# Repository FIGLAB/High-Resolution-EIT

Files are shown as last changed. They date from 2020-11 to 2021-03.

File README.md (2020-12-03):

# High-Resolution-EIT

The high resolution Electrical Impedance Tomograph (EIT) project is provided for academic and non-commercial research. This project is based on our publication at ACM UIST 2016: https://dl.acm.org/doi/abs/10.1145/2984511.2984574

## ACM Ref

Yang Zhang, Robert Xiao, and Chris Harrison. 2016. Advancing Hand Gesture Recognition with High Resolution Electrical Impedance Tomography. In Proceedings of the 29th Annual Symposium on User Interface Software and Technology (UIST '16). Association for Computing Machinery, New York, NY, USA, 843–850. DOI:https://doi.org/10.1145/2984511.2984574

## BibTex

```
@inproceedings{10.1145/2984511.2984574,
author = {Zhang, Yang and Xiao, Robert and Harrison, Chris},
title = {Advancing Hand Gesture Recognition with High Resolution Electrical Impedance Tomography},
year = {2016},
isbn = {9781450341899},
publisher = {Association for Computing Machinery},
address = {New York, NY, USA},
url = {https://doi.org/10.1145/2984511.2984574},
doi = {10.1145/2984511.2984574},
abstract = {Electrical Impedance Tomography (EIT) was recently employed in the HCI domain to detect hand gestures using an instrumented smartwatch. This prior work demonstrated great promise for non-invasive, high accuracy recognition of gestures for interactive control. We introduce a new system that offers improved sampling speed and resolution. In turn, this enables superior interior reconstruction and gesture recognition. More importantly, we use our new system as a vehicle for experimentation ' we compare two EIT sensing methods and three different electrode resolutions. Results from in-depth empirical evaluations and a user study shed light on the future feasibility of EIT for sensing human input.},
booktitle = {Proceedings of the 29th Annual Symposium on User Interface Software and Technology},
pages = {843–850},
numpages = {8},
keywords = {hand gestures, eit, electrical impedance tomography, biometrics, smartwatch, bio-impedance, input},
location = {Tokyo, Japan},
series = {UIST '16}
}
```

## Contact

For interests in commercialization, please reach out to CMU CTTEC for details at innovation@cmu.edu

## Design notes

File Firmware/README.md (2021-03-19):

# Firmware

IDE: Arduino with Teensyduino add-on 

Arduino: https://www.arduino.cc/en/software/
Teensyduino: https://www.pjrc.com/teensy/teensyduino.html

Firmware was tested with Arduino V1.6.5 and Teensyduino V1.40.

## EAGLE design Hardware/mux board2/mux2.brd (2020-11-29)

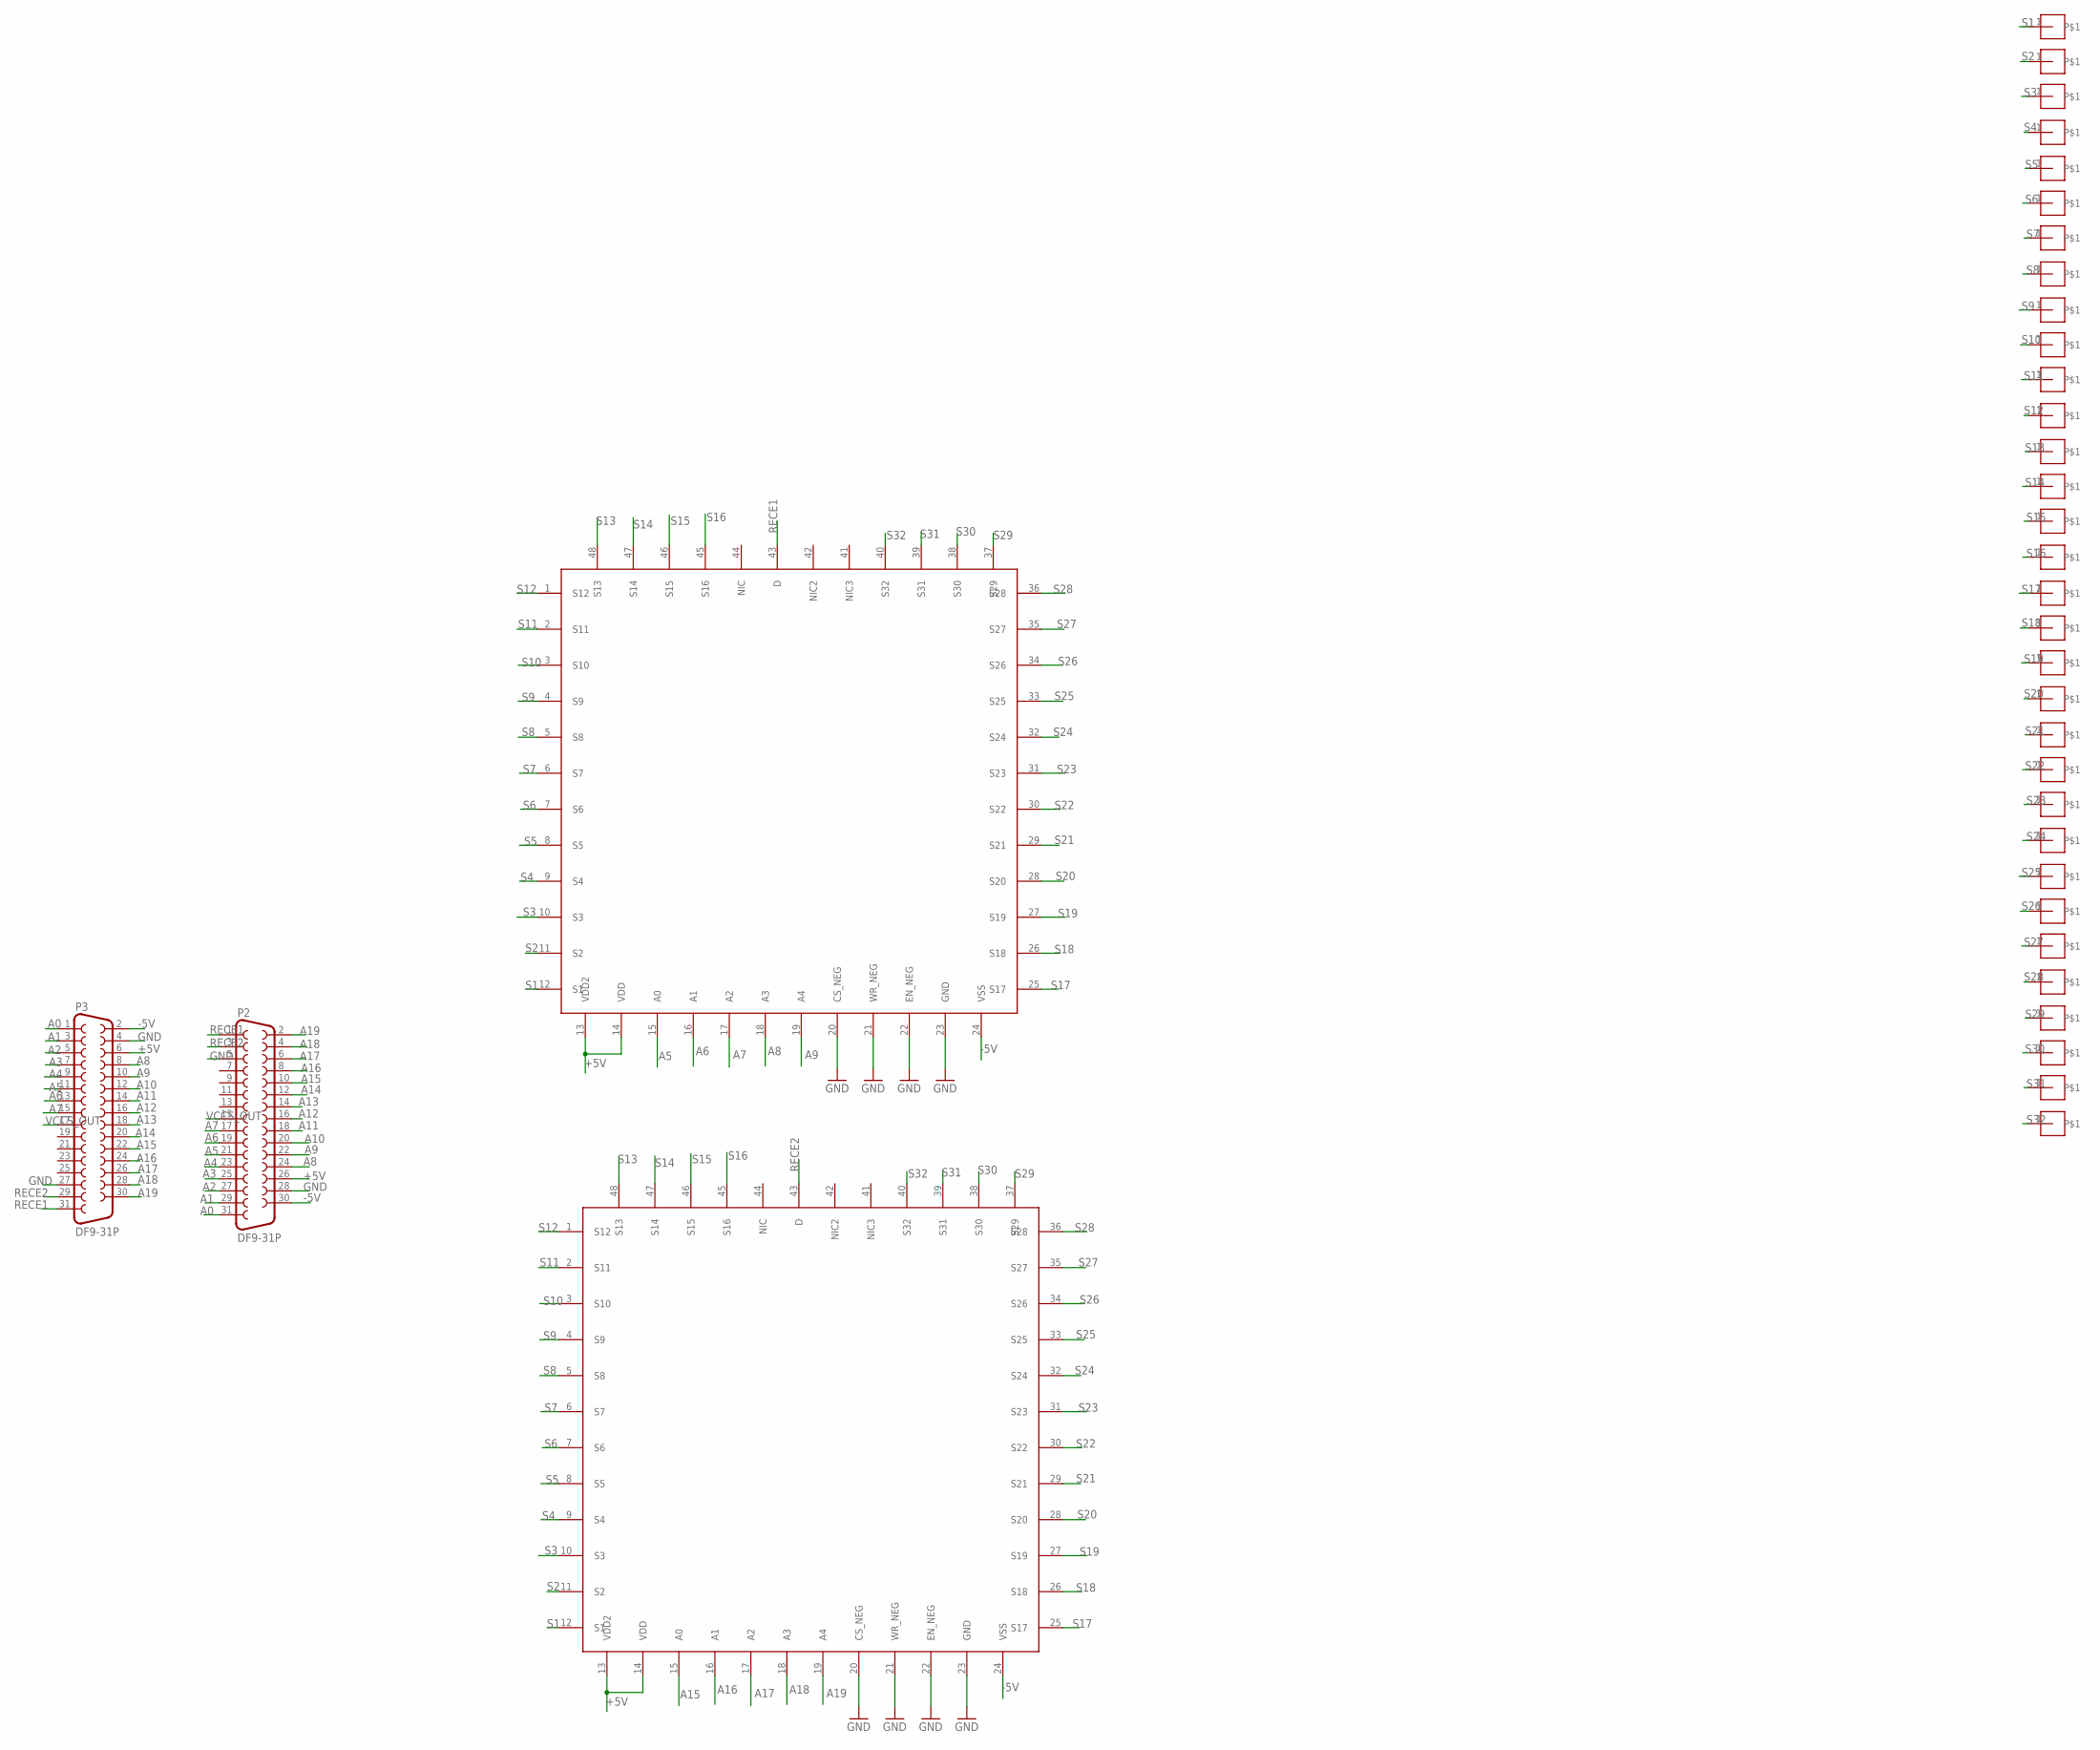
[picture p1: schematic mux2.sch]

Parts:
P2, P3: DF9-31P
U$25, U$26, U$27, U$28, U$29, U$30, U$31, U$32, U$33, U$34, U$35, U$36, U$37, U$38, U$39, U$40, U$41, U$42, U$43, U$44, U$45, U$46, U$47, U$48, U$49, U$50, U$51, U$52, U$53, U$54, U$55, U$56: M01
U$73, U$74: ADG732; TQFP48

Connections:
+5V: P2.26, P3.6, U$73.13 (VDD2), U$73.14 (VDD), U$74.13 (VDD2), U$74.14 (VDD)
-5V: P2.30, P3.2, U$73.24 (VSS), U$74.24 (VSS)
A0: P2.31, P3.1
A1: P2.29, P3.3
A2: P2.27, P3.5
A3: P2.25, P3.7
A4: P2.23, P3.9
A5: P2.21, P3.11, U$74.15 (A0)
A6: P2.19, P3.13, U$74.16 (A1)
A7: P2.17, P3.15, U$74.17 (A2)
A8: P2.24, P3.8, U$74.18 (A3)
A9: P2.22, P3.10, U$74.19 (A4)
A10: P2.20, P3.12
A11: P2.18, P3.14
A12: P2.16, P3.16
A13: P2.14, P3.18
A14: P2.12, P3.20
A15: P2.10, P3.22, U$73.15 (A0)
A16: P2.8, P3.24, U$73.16 (A1)
A17: P2.6, P3.26, U$73.17 (A2)
A18: P2.4, P3.28, U$73.18 (A3)
A19: P2.2, P3.30, U$73.19 (A4)
GND: P2.5, P2.28, P3.4, P3.27, U$73.20 (CS_NEG), U$73.21 (WR_NEG), U$73.22 (EN_NEG), U$73.23 (GND), U$74.20 (CS_NEG), U$74.21 (WR_NEG), U$74.22 (EN_NEG), U$74.23 (GND)
RECE1: P2.1, P3.31, U$74.43 (D)
RECE2: P2.3, P3.29, U$73.43 (D)
S1: U$25.1, U$73.12 (S1), U$74.12 (S1)
S2: U$26.1, U$73.11 (S2), U$74.11 (S2)
S3: U$27.1, U$73.10 (S3), U$74.10 (S3)
S4: U$28.1, U$73.9 (S4), U$74.9 (S4)
S5: U$29.1, U$73.8 (S5), U$74.8 (S5)
S6: U$30.1, U$73.7 (S6), U$74.7 (S6)
S7: U$31.1, U$73.6 (S7), U$74.6 (S7)
S8: U$32.1, U$73.5 (S8), U$74.5 (S8)
S9: U$33.1, U$73.4 (S9), U$74.4 (S9)
S10: U$34.1, U$73.3 (S10), U$74.3 (S10)
S11: U$35.1, U$73.2 (S11), U$74.2 (S11)
S12: U$36.1, U$73.1 (S12), U$74.1 (S12)
S13: U$37.1, U$73.48 (S13), U$74.48 (S13)
S14: U$38.1, U$73.47 (S14), U$74.47 (S14)
S15: U$39.1, U$73.46 (S15), U$74.46 (S15)
S16: U$40.1, U$73.45 (S16), U$74.45 (S16)
S17: U$41.1, U$73.25 (S17), U$74.25 (S17)
S18: U$42.1, U$73.26 (S18), U$74.26 (S18)
S19: U$43.1, U$73.27 (S19), U$74.27 (S19)
S20: U$44.1, U$73.28 (S20), U$74.28 (S20)
S21: U$45.1, U$73.29 (S21), U$74.29 (S21)
S22: U$46.1, U$73.30 (S22), U$74.30 (S22)
S23: U$47.1, U$73.31 (S23), U$74.31 (S23)
S24: U$48.1, U$73.32 (S24), U$74.32 (S24)
S25: U$49.1, U$73.33 (S25), U$74.33 (S25)
S26: U$50.1, U$73.34 (S26), U$74.34 (S26)
S27: U$51.1, U$73.35 (S27), U$74.35 (S27)
S28: U$52.1, U$73.36 (S28), U$74.36 (S28)
S29: U$53.1, U$73.37 (S29), U$74.37 (S29)
S30: U$54.1, U$73.38 (S30), U$74.38 (S30)
S31: U$55.1, U$73.39 (S31), U$74.39 (S31)
S32: U$56.1, U$73.40 (S32), U$74.40 (S32)
VCCS_OUT: P2.15, P3.17

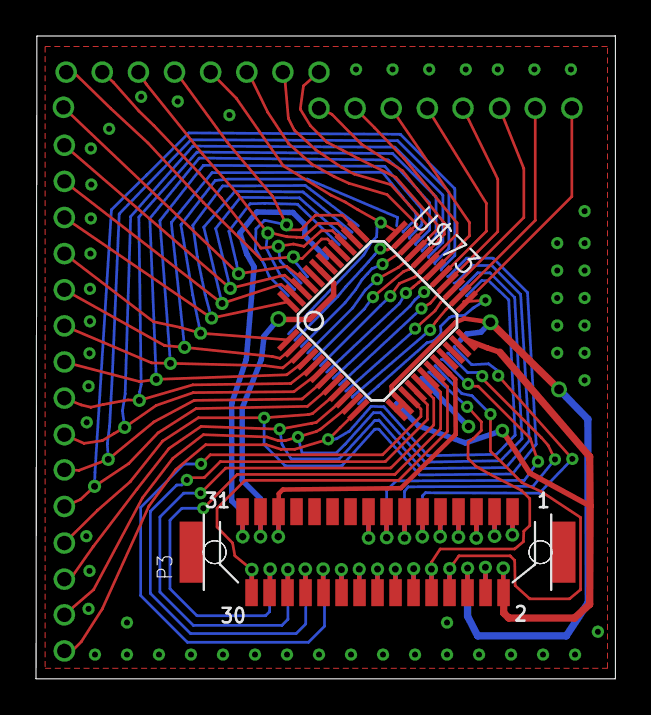
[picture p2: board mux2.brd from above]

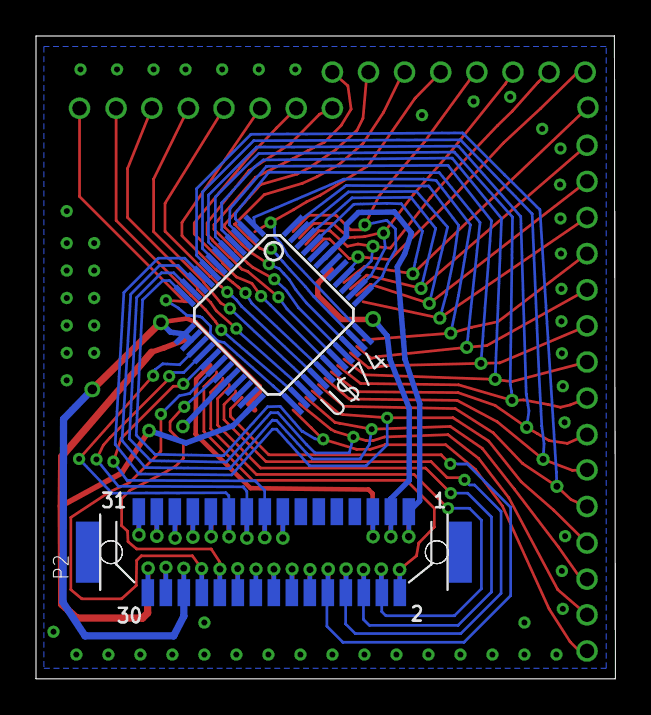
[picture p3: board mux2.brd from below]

Board: 2 copper layers, 32.2 x 35.7 mm, 36 parts (2 on the bottom side), 58 nets.

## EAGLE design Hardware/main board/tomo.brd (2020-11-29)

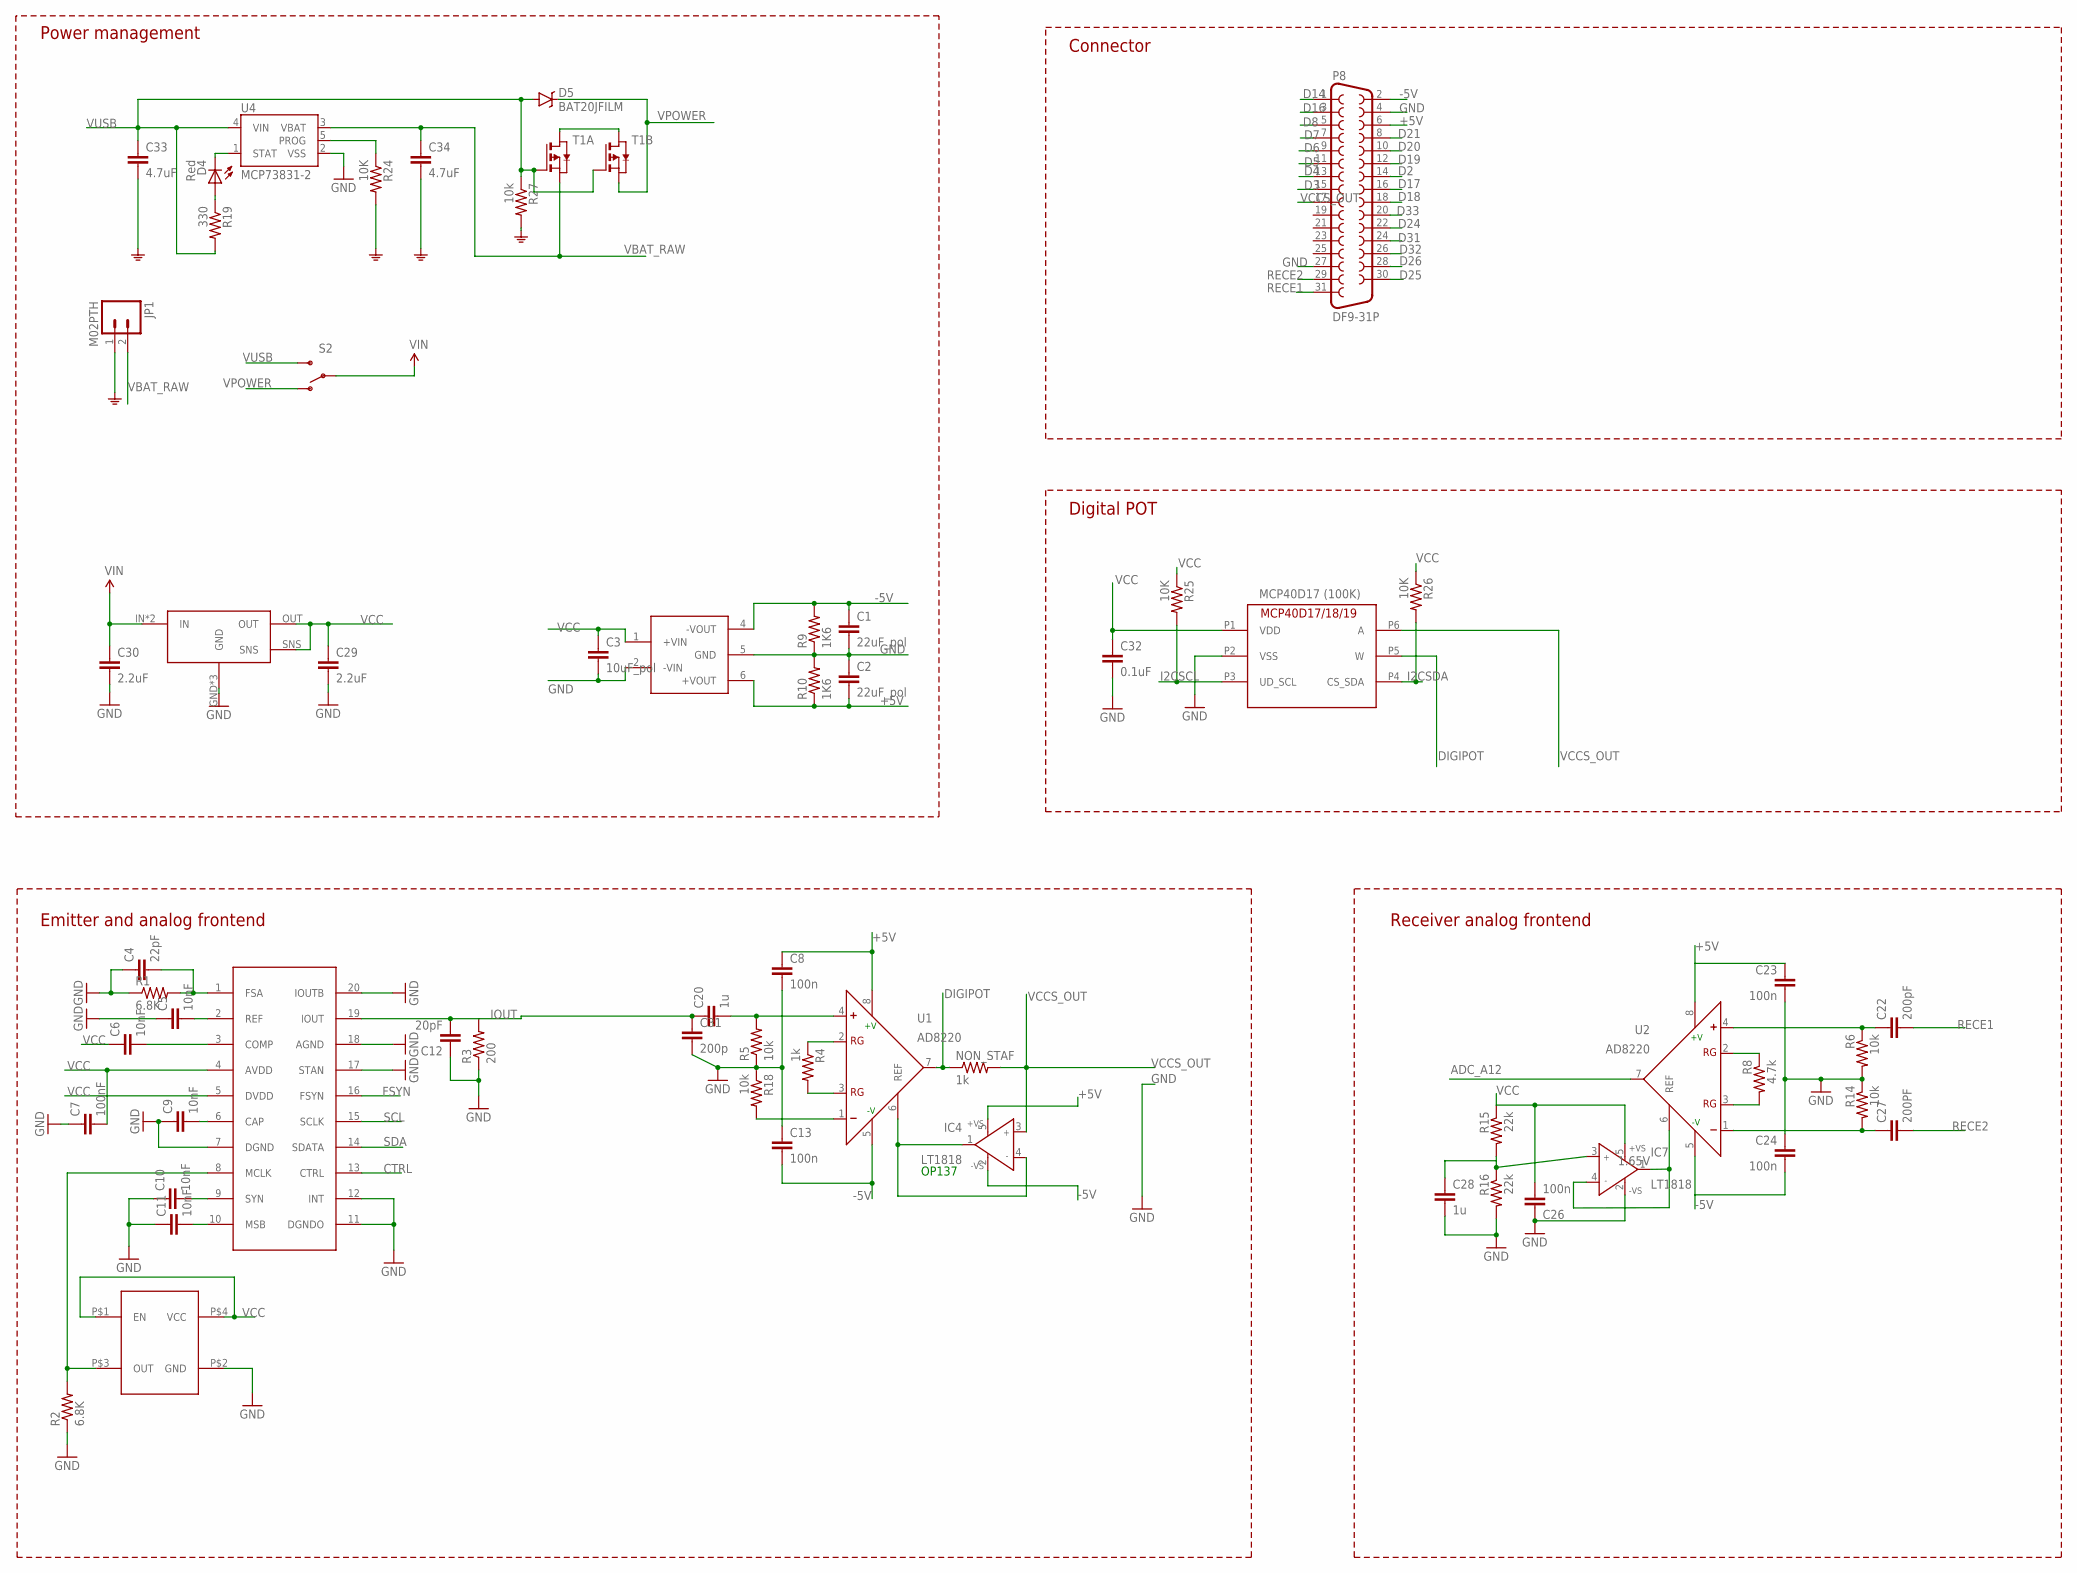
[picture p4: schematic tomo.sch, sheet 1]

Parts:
C1, C2: 22uF_pol; 0603-CAP
C3: 10uF_pol; 0603-CAP
C4: 22pF; 0603-CAP
C5, C6, C9, C10, C11: 10nF; 0603-CAP
C7: 100nF; 0603-CAP
C8, C13, C23, C24, C26: 100n; 0603-CAP
C12: 20pF; 0603-CAP
C20, C28: 1u; 0603-CAP
C22: 200pF; 0603-CAP
C27: 200PF; 0603-CAP
C29, C30: 2.2uF; 0402-CAP
C31: 200p; 0603-CAP
C32: 0.1uF; 0402-CAP
C33, C34: 4.7uF; 0402-CAP
D4: Red; LED-0603
D5: BAT20JFILM; SOD-323
IC4, IC7: LT1818; SOT23-5
JP1: M02PTH; 1X02
LP1: LP38691SD; WSON_6
NON_STAF: 1k; 0603-RES
P8: DF9-31P
R1, R2: 6.8K; 0603
R3: 200; 0603
R4: 1k; 0603-RES
R5, R18: 10k; 0603-RES
R6, R14: 10k; 0603
R8: 4.7k; 0603
R9, R10: 1K6; 0603-RES
R15, R16: 22k; 0603
R19: 330; 0402-RES
R24, R25, R26: 10K; 0402-RES
R27: 10k; 0402-RES
S2: SWITCH-SPDT-SMD-A; SWITCH-SPST-SMD-A
T1: BSS84DW; SOT363
U1, U2: AD8220; MSOP8
U4: MCP73831-2; SOT23-5
U$2: AD5930; TSSOP-20
U$3: OSC
U$4: DCDC_CONVERTOR
U$6: MCP40D17/18/19; SC70-6

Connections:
1.65V: IC7.1 (OUT), IC7.4 (IN-), U2.6 (REF)
+5V: C2.2, C8.1, C23.1, IC4.5 (+VS), P8.6, R10.1, U1.8 (+V), U2.8 (+V), U$4.6 (+VOUT)
-5V: C1.1, C13.2, C24.2, IC4.2 (-VS), P8.2, R9.2, U1.5 (-V), U2.5 (-V), U$4.4 (-VOUT)
ADC_A12: U2.7 (OUT); also elsewhere on the board
CTRL: U$2.13 (CTRL); also elsewhere on the board
D2: P8.14; also elsewhere on the board
D3: P8.15; also elsewhere on the board
D4: P8.13; also elsewhere on the board
D5: P8.11; also elsewhere on the board
D6: P8.9; also elsewhere on the board
D7: P8.7; also elsewhere on the board
D8: P8.5; also elsewhere on the board
D14: P8.1; also elsewhere on the board
D16: P8.3; also elsewhere on the board
D17: P8.16; also elsewhere on the board
D18: P8.18; also elsewhere on the board
D19: P8.12; also elsewhere on the board
D20: P8.10; also elsewhere on the board
D21: P8.8; also elsewhere on the board
D24: P8.22; also elsewhere on the board
D25: P8.30; also elsewhere on the board
D26: P8.28; also elsewhere on the board
D31: P8.24; also elsewhere on the board
D32: P8.26; also elsewhere on the board
D33: P8.20; also elsewhere on the board
DIGIPOT: NON_STAF.1, U1.7 (OUT), U$6.P5 (W)
FSYN: U$2.16 (FSYN); also elsewhere on the board
GND: C1.2, C2.1, C3.2, C4.1, C5.1, C7.1, C8.2, C9.1, C10.1, C11.1, C12.1, C13.1, C23.2, C24.1, C26.1, C28.2, C29.2, C30.2, C31.2, C32.2, C33.2, C34.2, IC7.2 (-VS), JP1.1, LP1.GND, LP1.N/C (GND), LP1.THERMAL (GND), P8.4, P8.27, R1.1, R2.1, R3.1, R5.1, R6.2, R9.1, R10.2, R14.1, R16.2, R18.1, R24.2, R27.2, U4.2 (VSS), U$2.7 (DGND), U$2.11 (DGNDO), U$2.12 (INT), U$2.17 (STAN), U$2.18 (AGND), U$2.20 (IOUTB), U$3.P$2 (GND), U$4.2 (-VIN), U$4.5 (GND), U$6.P2 (VSS); also elsewhere on the board
I2CSCL: R25.2, U$6.P3 (UD_SCL); also elsewhere on the board
I2CSDA: R26.2, U$6.P4 (CS_SDA); also elsewhere on the board
IOUT: C12.2, C20.1, C31.1, R3.2, U$2.19 (IOUT)
unnamed: C4.2, R1.2, U$2.1 (FSA)
unnamed: C6.2, U$2.3 (COMP)
unnamed: C5.2, U$2.2 (REF)
unnamed: C9.2, U$2.6 (CAP)
unnamed: R2.2, U$2.8 (MCLK), U$3.P$3 (OUT)
unnamed: C10.2, U$2.9 (SYN)
unnamed: C11.2, U$2.10 (MSB)
unnamed: R4.1, U1.2 (RG)
unnamed: C28.1, IC7.3 (IN+), R15.2, R16.1
unnamed: C20.2, R5.2, U1.4 (+)
unnamed: R4.2, U1.3 (RG)
unnamed: IC4.1 (OUT), IC4.4 (IN-), U1.6 (REF)
unnamed: R18.2, U1.1 (-)
unnamed: D4.A, R19.1
unnamed: T1.3 (D), T1.6 (D)
unnamed: C22.1, R6.1, U2.4 (+)
unnamed: C27.1, R14.2, U2.1 (-)
unnamed: R8.1, U2.2 (RG)
unnamed: R8.2, U2.3 (RG)
PROG: R24.1, U4.5 (PROG)
RECE1: C22.2, P8.31
RECE2: C27.2, P8.29
SCL: U$2.15 (SCLK); also elsewhere on the board
SDA: U$2.14 (SDATA); also elsewhere on the board
STAT: D4.C, U4.1 (STAT)
VBAT_RAW: C34.1, JP1.2, T1.4 (S), U4.3 (VBAT)
VCC: C3.1, C6.1, C7.2, C26.2, C29.1, C32.1, IC7.5 (+VS), LP1.OUT, LP1.SNS, R15.1, R25.1, R26.1, U$2.4 (AVDD), U$2.5 (DVDD), U$3.P$1 (EN), U$3.P$4 (VCC), U$4.1 (+VIN), U$6.P1 (VDD)
VCCS_OUT: IC4.3 (IN+), NON_STAF.2, P8.17, U$6.P6 (A)
VIN: C30.1, LP1.IN, LP1.IN2 (IN), S2.2; also elsewhere on the board
VPOWER: D5.C, S2.1 (O), T1.1 (S)
VUSB: C33.1, D5.A, R19.2, R27.1, S2.3 (S), T1.2 (G), T1.5 (G), U4.4 (VIN); also elsewhere on the board

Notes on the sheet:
OP137
MCP40D17 (100K)
Power management
Connector
Digital POT
Emitter and analog frontend
Receiver analog frontend

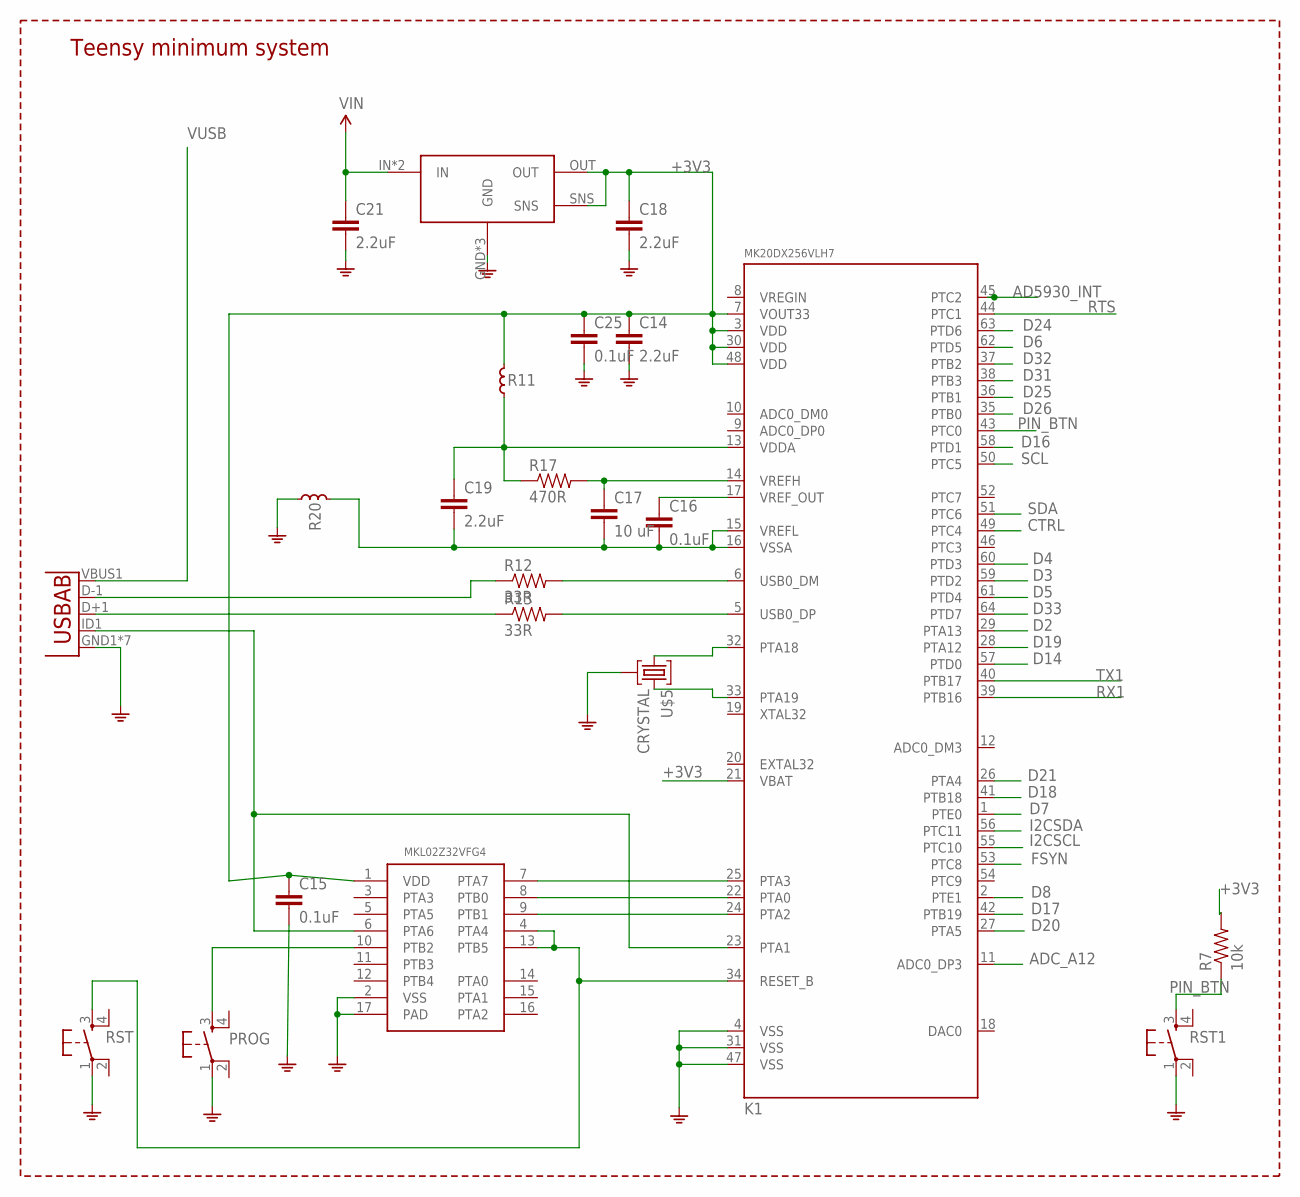
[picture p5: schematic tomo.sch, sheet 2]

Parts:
C14: 2.2uF; 0603-CAP
C15, C16, C25: 0.1uF; 0402-CAP
C17: 10 uF; 0402-CAP
C18, C19, C21: 2.2uF; 0402-CAP
K1: MK20DX256VLH7; LQFP64-05
LP38691: LP38691SD; WSON_6
PROG: KMR211GLFS; TACTILE_SWITCH_SMD
R7: 10k; 0402-RES
R11, R20: FERRITE; L0603
R12, R13: 33R; 0402-RES
R17: 470R; 0402-RES
RST, RST1: KMR211GLFS; TACTILE_SWITCH_SMD
U5: USB""; USB-MICRO-SMD
U$5: CRYSTAL
U$14: MKL02Z32VFG4_; QFN16_3X3

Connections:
+3V3: C14.1, C15.1, C18.1, C25.1, K1.3 (VDD), K1.7 (VOUT33), K1.21 (VBAT), K1.30 (VDD), K1.48 (VDD), LP38691.OUT, LP38691.SNS, R7.2, R11.2, U$14.1 (VDD); also elsewhere on the board
AD5930_INT: K1.45 (PTC2)
ADC_A12: K1.11 (ADC0_DP3); also elsewhere on the board
CTRL: K1.49 (PTC4); also elsewhere on the board
D2: K1.29 (PTA13); also elsewhere on the board
D3: K1.59 (PTD2); also elsewhere on the board
D4: K1.60 (PTD3); also elsewhere on the board
D5: K1.61 (PTD4); also elsewhere on the board
D6: K1.62 (PTD5); also elsewhere on the board
D7: K1.1 (PTE0); also elsewhere on the board
D8: K1.2 (PTE1); also elsewhere on the board
D14: K1.57 (PTD0); also elsewhere on the board
D16: K1.58 (PTD1); also elsewhere on the board
D17: K1.42 (PTB19); also elsewhere on the board
D18: K1.41 (PTB18); also elsewhere on the board
D19: K1.28 (PTA12); also elsewhere on the board
D20: K1.27 (PTA5); also elsewhere on the board
D21: K1.26 (PTA4); also elsewhere on the board
D24: K1.63 (PTD6); also elsewhere on the board
D25: K1.36 (PTB1); also elsewhere on the board
D26: K1.35 (PTB0); also elsewhere on the board
D31: K1.38 (PTB3); also elsewhere on the board
D32: K1.37 (PTB2); also elsewhere on the board
D33: K1.64 (PTD7); also elsewhere on the board
FSYN: K1.53 (PTC8); also elsewhere on the board
GND: C14.2, C15.2, C18.2, C21.2, C25.2, K1.4 (VSS), K1.31 (VSS), K1.47 (VSS), LP38691.GND, LP38691.N/C (GND), LP38691.THERMAL (GND), PROG.1, R20.1, RST.1, RST1.1, U5.GND1 (GND), U5.P$1 (GND), U5.P$2 (GND), U5.P$3 (GND), U5.P$4 (GND), U5.P$5 (GND), U5.P$6 (GND), U$5.GND1 (2), U$5.GND2 (2), U$14.2 (VSS), U$14.17 (PAD); also elsewhere on the board
I2CSCL: K1.55 (PTC10); also elsewhere on the board
I2CSDA: K1.56 (PTC11); also elsewhere on the board
unnamed: K1.24 (PTA2), U$14.9 (PTB1)
unnamed: K1.5 (USB0_DP), R13.2
unnamed: K1.6 (USB0_DM), R12.2
unnamed: R13.1, U5.D+1 (D+)
unnamed: C16.1, K1.17 (VREF_OUT)
unnamed: R12.1, U5.D-1 (D-)
unnamed: K1.23 (PTA1), U5.ID1 (USBID), U$14.6 (PTA6)
unnamed: K1.22 (PTA0), U$14.8 (PTB0)
unnamed: K1.32 (PTA18), U$5.SIG1 (1)
unnamed: K1.33 (PTA19), U$5.SIG2 (3)
unnamed: C17.1, K1.14 (VREFH), R17.2
unnamed: C16.2, C17.2, C19.2, K1.15 (VREFL), K1.16 (VSSA), R20.2
unnamed: C19.1, K1.13 (VDDA), R11.1, R17.1
unnamed: PROG.3, U$14.10 (PTB2)
unnamed: K1.25 (PTA3), U$14.7 (PTA7)
PIN_BTN: K1.43 (PTC0), R7.1, RST1.3
RST: K1.34 (RESET_B), RST.3, U$14.4 (PTA4), U$14.13 (PTB5)
RTS: K1.44 (PTC1); also elsewhere on the board
RX1: K1.39 (PTB16); also elsewhere on the board
SCL: K1.50 (PTC5); also elsewhere on the board
SDA: K1.51 (PTC6); also elsewhere on the board
TX1: K1.40 (PTB17); also elsewhere on the board
VIN: C21.1, LP38691.IN, LP38691.IN2 (IN); also elsewhere on the board
VUSB: U5.VBUS1 (VBUS); also elsewhere on the board

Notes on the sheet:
Teensy minimum system

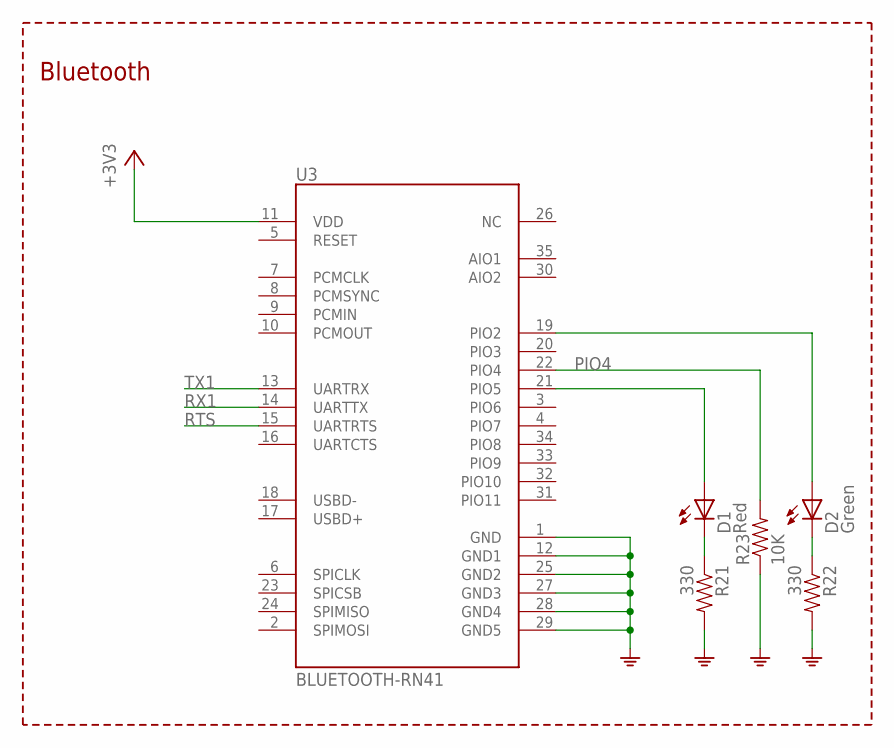
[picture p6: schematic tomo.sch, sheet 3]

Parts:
D1: Red; LED-0603
D2: Green; LED-0603
R21, R22: 330; 0402-RES
R23: 10K; 0402-RES
U3: BLUETOOTH-RN41; RN41

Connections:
+3V3: U3.11 (VDD); also elsewhere on the board
D1: D1.C, R21.1
D9: D2.C, R22.1
GND: R21.2, R22.2, R23.1, U3.1 (GND), U3.12 (GND1), U3.25 (GND2), U3.27 (GND3), U3.28 (GND4), U3.29 (GND5); also elsewhere on the board
unnamed: D1.A, U3.21 (PIO5)
unnamed: D2.A, U3.19 (PIO2)
PIO4: R23.2, U3.22 (PIO4)
RTS: U3.15 (UARTRTS); also elsewhere on the board
RX1: U3.14 (UARTTX); also elsewhere on the board
TX1: U3.13 (UARTRX); also elsewhere on the board

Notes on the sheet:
Bluetooth

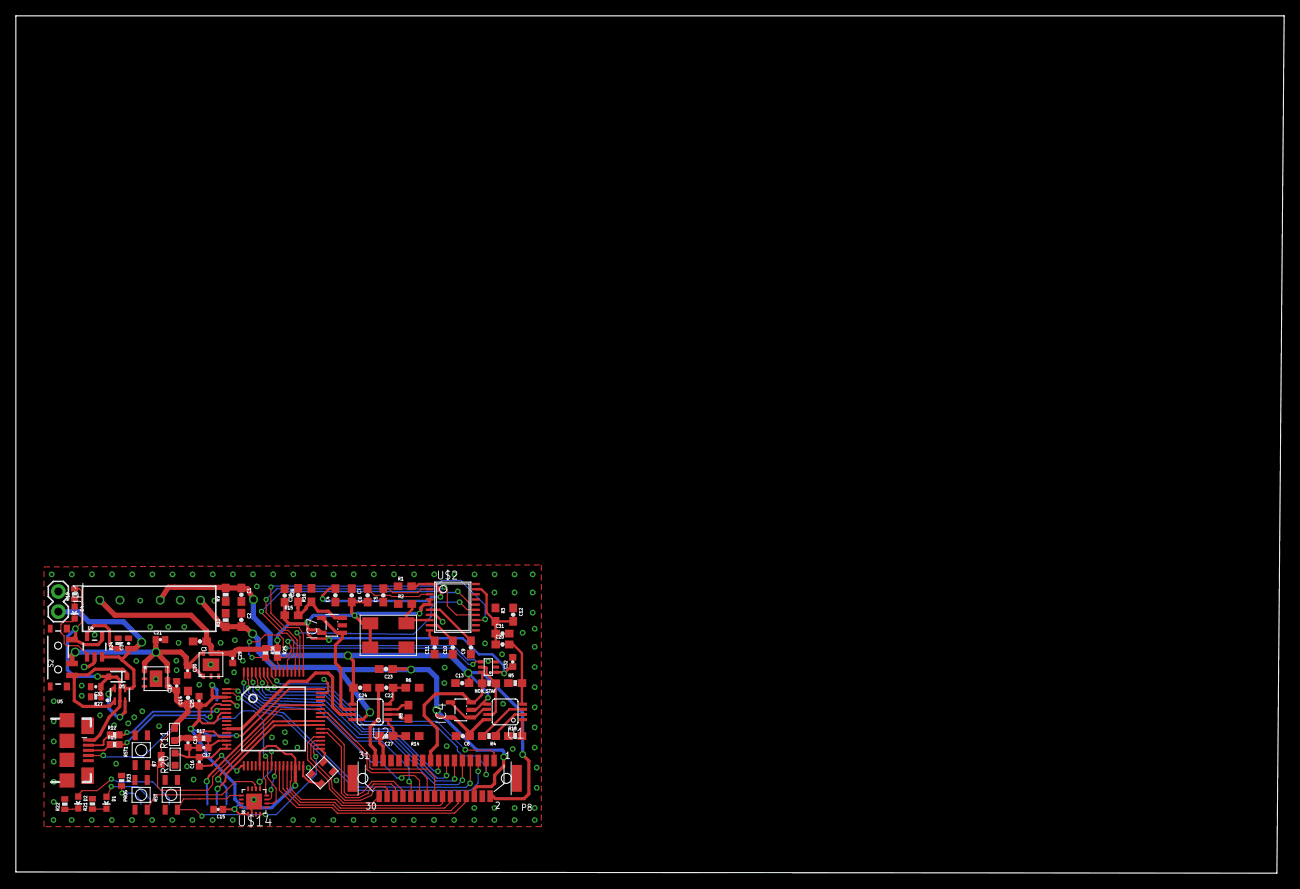
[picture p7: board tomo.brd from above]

Board: 2 copper layers, 160.0 x 108.2 mm, 89 parts (1 on the bottom side), 88 nets.

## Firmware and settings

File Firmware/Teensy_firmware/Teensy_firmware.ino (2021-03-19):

#include <ADC.h>
#include <SPI.h>
#include <i2c_t3.h>
#include "AD5930.h"
#include "Multiplex_4pole.h"
#include "Multiplex_2pole.h"
#include "fastadc.h"

// ship all measurements including the escape pairs
#define numElectrode 8
#define SAMPLE_SIZE 500 // doubled the sample size for 4MHz ADC sampling 
#define SETTLEDOWM_DELAY 100

// measure on emitting pairs
bool all = false; // send 

// Digital Pot
#define POT_ADDR 0x2E

/* AD5930 */
AD5930 ad5930;

/* for adc */
#define DC_BIAS_12RES 2096


#define NUM_MEAS (numElectrode*numElectrode)
uint32_t abdcPortVectors[NUM_MEAS * 4];

uint16_t input_buffer[SAMPLE_SIZE];

#define ADCBUF_COUNT 4096
static uint16_t read_buf[ADCBUF_COUNT];
const int readPin = A12;

/* for Serial communication */
uint16_t send_buffer[NUM_MEAS];

/* ADC helper inline function */
#define ADC_BITBAND_ADDR(reg, bit) (((uint32_t)(reg) - 0x40000000) * 32 + (bit) * 4 + 0x42000000)

__attribute__((always_inline)) volatile bool getBit(volatile uint32_t* reg, uint8_t bit) {
        return (volatile bool)*(uint32_t*)(ADC_BITBAND_ADDR(reg, bit));
}

void setup() {


  #if 1 // or 0 to use NON_STAF on the pcb to replace digipot
  // reassign pins 29 and 30 to use the ALT2 configuration
  // which makes them  I2C pins - I2C1_SCL (pin29) and I2C1_SDA (pin30)
  CORE_PIN29_CONFIG = PORT_PCR_MUX(2);
  CORE_PIN30_CONFIG = PORT_PCR_MUX(2);
  
  // Initialize digital pot (Using I2C1 rather than I2C0 to avoid using portB)
  Wire1.begin(I2C_MASTER, 0x00, I2C_PINS_29_30, I2C_PULLUP_EXT, I2C_RATE_100); // default clock speed 100KHz
  // command code 0x0 : directly write to the scale register
  // scale can be set from 0x0 to 0x7F (128 possible settings)
  // resistance range is from 0 to 100kOhm
  Wire1.beginTransmission(POT_ADDR);
  Wire1.send(0x00);
  Wire1.send(0x7F); //0x0d roughly 10k ref resistor
  Wire1.endTransmission();
 #endif 

 delay(10);

  // Initialize port vector look up table for multiplexing
  if(all == true){
    if(numElectrode == 32){
    memcpy(abdcPortVectors, abdcPortVectors32all, sizeof(abdcPortVectors32all));
    }else if (numElectrode == 16){
      memcpy(abdcPortVectors, abdcPortVectors16all, sizeof(abdcPortVectors16all));
    }else if (numElectrode == 8){
      memcpy(abdcPortVectors, abdcPortVectors16all, sizeof(abdcPortVectors8all));
    }
  }

  else{
    if(numElectrode == 32){
    memcpy(abdcPortVectors, abdcPortVectors32part, sizeof(abdcPortVectors32part));
    }else if (numElectrode == 16){
      memcpy(abdcPortVectors, abdcPortVectors16part, sizeof(abdcPortVectors16part));
    }else if (numElectrode == 8){
      memcpy(abdcPortVectors, abdcPortVectors8part, sizeof(abdcPortVectors8part));
    }
  }
  
  // Initialize FAST ADC
  Serial.begin(460800);
  pinMode(readPin, INPUT);

  // Initialize multiplexer control pins
  for(int i = 0; i < 20; i++){
    pinMode(pinForMul[i],OUTPUT);
  }
  delay(100);

  // initialize the output pins for AD5930
  ad5930.myBegin();
  delay(10);
  ad5930.startEmitting();

  // initialize dual dma mode adc sampling
  startDualADC(readPin, read_buf, ADCBUF_COUNT);
  memset(input_buffer, 0, sizeof(input_buffer));
}

void loop() {
  
  for(int i = 0; i < NUM_MEAS; i++){

    
    // escape emitting ports
    if(abdcPortVectors[i * 4] == 7 ){
      send_buffer[i] = 2000; // skip emit rece overlapping measurements
    }else{
      switchForMeasure(i);
      
      delayMicroseconds(SETTLEDOWM_DELAY); // should be variated to wait for mul to stable
      
      do_one_sample();
      send_buffer[i] = escapeTerminator(get_rms(input_buffer));
      
    }
  }
  // send measurements 
  #if 1
    Serial.write((uint8_t *)send_buffer, sizeof(send_buffer));
    Serial.write(0x80);
  #endif

  delay(20);
}

/******************/
/* Serial helpers */
/******************/
static inline uint16_t escapeTerminator (uint16_t v){
  if((v & 0xff) == 0x80){
    v++;
  }

  if((v >> 8) == 0x80){
    v += 0x100 - (v & 0xff); 
  }
  return v;
}

/***************/
/* ADC helpers */
/***************/
static void do_one_sample() { 
    extractDMASamples(read_buf, ADCBUF_COUNT, (uint16_t *)input_buffer, SAMPLE_SIZE);
}

static uint16_t get_rms(uint16_t *input_buffer){
  uint32_t rst = 0;
  for(int i = 0; i < SAMPLE_SIZE; i++){
    rst += (DC_BIAS_12RES - input_buffer[i]) * (DC_BIAS_12RES - input_buffer[i]) ;
  }

  rst = sqrt(rst / SAMPLE_SIZE);
  //rst = (rst / SAMPLE_SIZE); // save sqrt for laptop

  if(rst == 2000){ // escape dummy
    rst = 1999;
  }
  
  return (uint16_t)rst;
}

/***************/
/* MUL helpers */
/***************/
static inline void switchForMeasure(int num){ // num is from 0 to 1023
  int base = num * 4;
    GPIOA_PDOR = abdcPortVectors[base];
    GPIOB_PDOR = abdcPortVectors[base + 1];
    GPIOD_PDOR = abdcPortVectors[base + 2];
    GPIOE_PDOR = abdcPortVectors[base + 3];
}

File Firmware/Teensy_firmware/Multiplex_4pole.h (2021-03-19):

int pinForMul[] = {14,16,8,7,6,5,4,3,21,20,19,2,17,18,33,24,31,32,26,25};

// all port vector lookup tables for multiplexing

uint32_t abdcPortVectors32part[] = {
	
	7,7,7,7,       //0 === 0 31 0 31
	7,7,7,7,       //1 === 0 31 1 0
	0,0,107,3,       //2 === 0 31 2 1
	0,8,59,3,       //3 === 0 31 3 2
	0,8,103,3,       //4 === 0 31 4 3
	0,4,55,3,       //5 === 0 31 5 4
	0,4,111,3,       //6 === 0 31 6 5
	0,12,63,3,       //7 === 0 31 7 6
	16,12,99,3,       //8 === 0 31 8 7
	16,1,51,3,       //9 === 0 31 9 8
	16,1,107,3,       //10 === 0 31 10 9
	16,9,59,3,       //11 === 0 31 11 10
	16,9,103,3,       //12 === 0 31 12 11
	16,5,55,3,       //13 === 0 31 13 12
	16,5,111,3,       //14 === 0 31 14 13
	16,13,63,3,       //15 === 0 31 15 14
	32,13,99,3,       //16 === 0 31 16 15
	32,2,51,3,       //17 === 0 31 17 16
	32,2,107,3,       //18 === 0 31 18 17
	32,10,59,3,       //19 === 0 31 19 18
	32,10,103,3,       //20 === 0 31 20 19
	32,6,55,3,       //21 === 0 31 21 20
	32,6,111,3,       //22 === 0 31 22 21
	32,14,63,3,       //23 === 0 31 23 22
	48,14,99,3,       //24 === 0 31 24 23
	48,3,51,3,       //25 === 0 31 25 24
	48,3,107,3,       //26 === 0 31 26 25
	48,11,59,3,       //27 === 0 31 27 26
	48,11,103,3,       //28 === 0 31 28 27
	48,7,55,3,       //29 === 0 31 29 28
	48,7,111,3,       //30 === 0 31 30 29
	7,7,7,7,       //31 === 0 31 31 30
	7,7,7,7,       //32 === 1 0 0 31
	7,7,7,7,       //33 === 1 0 1 0
	7,7,7,7,       //34 === 1 0 2 1
	4096,8,24,0,       //35 === 1 0 3 2
	4096,8,68,0,       //36 === 1 0 4 3
	4096,4,20,0,       //37 === 1 0 5 4
	4096,4,76,0,       //38 === 1 0 6 5
	4096,12,28,0,       //39 === 1 0 7 6
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
};


uint32_t abdcPortVectors16part[] = {
	7,7,7,7,       //0 === 0 30 0 30
	7,7,7,7,       //1 === 0 30 2 0
	0,8,38,3,       //2 === 0 30 4 2
	0,4,46,3,       //3 === 0 30 6 4
	16,12,34,3,       //4 === 0 30 8 6
	16,1,42,3,       //5 === 0 30 10 8
	16,9,38,3,       //6 === 0 30 12 10
	16,5,46,3,       //7 === 0 30 14 12
	32,13,34,3,       //8 === 0 30 16 14
	32,2,42,3,       //9 === 0 30 18 16
	32,10,38,3,       //10 === 0 30 20 18
	32,6,46,3,       //11 === 0 30 22 20
	48,14,34,3,       //12 === 0 30 24 22
	48,3,42,3,       //13 === 0 30 26 24
	48,11,38,3,       //14 === 0 30 28 26
	7,7,7,7,       //15 === 0 30 30 28
	7,7,7,7,       //16 === 2 0 0 30
	7,7,7,7,       //17 === 2 0 2 0
	7,7,7,7,       //18 === 2 0 4 2
	8192,4,12,0,       //19 === 2 0 6 4
	8208,12,0,0,       //20 === 2 0 8 6
	8208,1,8,0,       //21 === 2 0 10 8
	8208,9,4,0,       //22 === 2 0 12 10
	8208,5,12,0,       //23 === 2 0 14 12
	8224,13,0,0,       //24 === 2 0 16 14
	8224,2,8,0,       //25 === 2 0 18 16
	8224,10,4,0,       //26 === 2 0 20 18
	8224,6,12,0,       //27 === 2 0 22 20
	8240,14,0,0,       //28 === 2 0 24 22
	8240,3,8,0,       //29 === 2 0 26 24
	8240,11,4,0,       //30 === 2 0 28 26
	8240,7,12,0,       //31 === 2 0 30 28
	0,524303,2,0,       //32 === 4 2 0 30
	7,7,7,7,       //33 === 4 2 2 0
	7,7,7,7,       //34 === 4 2 4 2
	7,7,7,7,       //35 === 4 2 6 4
	16,524300,2,0,       //36 === 4 2 8 6
	16,524289,10,0,       //37 === 4 2 10 8
	16,524297,6,0,       //38 === 4 2 12 10
	16,524293,14,0,       //39 === 4 2 14 12
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
};

uint32_t abdcPortVectors8part[] = {
7,7,7,7,       //0 === 0 7 0 7
7,7,7,7,       //1 === 0 7 1 0
0,0,75,2,       //2 === 0 7 2 1
0,8,27,2,       //3 === 0 7 3 2
0,8,71,2,       //4 === 0 7 4 3
0,4,23,2,       //5 === 0 7 5 4
0,4,79,2,       //6 === 0 7 6 5
7,7,7,7,       //7 === 0 7 7 6
7,7,7,7,       //8 === 1 0 0 7
7,7,7,7,       //9 === 1 0 1 0
7,7,7,7,       //10 === 1 0 2 1
4096,8,24,0,       //11 === 1 0 3 2
4096,8,68,0,       //12 === 1 0 4 3
4096,4,20,0,       //13 === 1 0 5 4
4096,4,76,0,       //14 === 1 0 6 5
4096,12,28,0,       //15 === 1 0 7 6
8192,12,65,0,       //16 === 2 1 0 7
7,7,7,7,       //17 === 2 1 1 0
7,7,7,7,       //18 === 2 1 2 1
7,7,7,7,       //19 === 2 1 3 2
8192,8,69,0,       //20 === 2 1 4 3
8192,4,21,0,       //21 === 2 1 5 4
8192,4,77,0,       //22 === 2 1 6 5
8192,12,29,0,       //23 === 2 1 7 6
12288,12,66,0,       //24 === 3 2 0 7
12288,0,18,0,       //25 === 3 2 1 0
7,7,7,7,       //26 === 3 2 2 1
7,7,7,7,       //27 === 3 2 3 2
7,7,7,7,       //28 === 3 2 4 3
12288,4,22,0,       //29 === 3 2 5 4
12288,4,78,0,       //30 === 3 2 6 5
12288,12,30,0,       //31 === 3 2 7 6
0,524300,67,0,       //32 === 4 3 0 7
0,524288,19,0,       //33 === 4 3 1 0
0,524288,75,0,       //34 === 4 3 2 1
7,7,7,7,       //35 === 4 3 3 2
7,7,7,7,       //36 === 4 3 4 3
7,7,7,7,       //37 === 4 3 5 4
0,524292,79,0,       //38 === 4 3 6 5
0,524300,31,0,       //39 === 4 3 7 6
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
};

uint32_t abdcPortVectors8part_2[] = {
	7,7,7,7,       //0 === 0 28 0 28
	7,7,7,7,       //1 === 0 28 4 0
	16,4,32,3,       //2 === 0 28 8 4
	16,1,36,3,       //3 === 0 28 12 8
	32,5,32,3,       //4 === 0 28 16 12
	32,2,36,3,       //5 === 0 28 20 16
	48,6,32,3,       //6 === 0 28 24 20
	7,7,7,7,       //7 === 0 28 28 24
	7,7,7,7,       //8 === 4 0 0 28
	7,7,7,7,       //9 === 4 0 4 0
	7,7,7,7,       //10 === 4 0 8 4
	16,524289,4,0,       //11 === 4 0 12 8
	32,524293,0,0,       //12 === 4 0 16 12
	32,524290,4,0,       //13 === 4 0 20 16
	48,524294,0,0,       //14 === 4 0 24 20
	48,524291,4,0,       //15 === 4 0 28 24
	0,262151,0,2,       //16 === 8 4 0 28
	7,7,7,7,       //17 === 8 4 4 0
	7,7,7,7,       //18 === 8 4 8 4
	7,7,7,7,       //19 === 8 4 12 8
	32,262149,0,2,       //20 === 8 4 16 12
	32,262146,4,2,       //21 === 8 4 20 16
	48,262150,0,2,       //22 === 8 4 24 20
	48,262147,4,2,       //23 === 8 4 28 24
	0,786439,0,1,       //24 === 12 8 0 28
	0,786432,4,1,       //25 === 12 8 4 0
	7,7,7,7,       //26 === 12 8 8 4
	7,7,7,7,       //27 === 12 8 12 8
	7,7,7,7,       //28 === 12 8 16 12
	32,786434,4,1,       //29 === 12 8 20 16
	48,786438,0,1,       //30 === 12 8 24 20
	48,786435,4,1,       //31 === 12 8 28 24
	0,7,128,3,       //32 === 16 12 0 28
	0,0,132,3,       //33 === 16 12 4 0
	16,4,128,3,       //34 === 16 12 8 4
	7,7,7,7,       //35 === 16 12 12 8
	7,7,7,7,       //36 === 16 12 16 12
	7,7,7,7,       //37 === 16 12 20 16
	48,6,128,3,       //38 === 16 12 24 20
	48,3,132,3,       //39 === 16 12 28 24
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
};



uint32_t abdcPortVectors16all[] = {
};


uint32_t abdcPortVectors32all[] = {
};


uint32_t abdcPortVectors8all[] = {
};

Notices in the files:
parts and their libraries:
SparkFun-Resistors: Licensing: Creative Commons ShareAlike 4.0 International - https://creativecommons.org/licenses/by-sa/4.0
